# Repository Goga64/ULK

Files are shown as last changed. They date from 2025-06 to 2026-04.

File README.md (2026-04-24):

# ULK

Low profile split keyboard with Corne 42 Layout and Cherry ULP switches. Made to be used on top of a laptop keyboard to provide the ultimate split experience on the go. 

## Contents
   - [Description](#Description)
   - [Gallery](#Gallery)
   - [BOM](#BOM)
   - [Firmware](#Firmware)
   - [Inspirations](#Inspirations)
     
169full
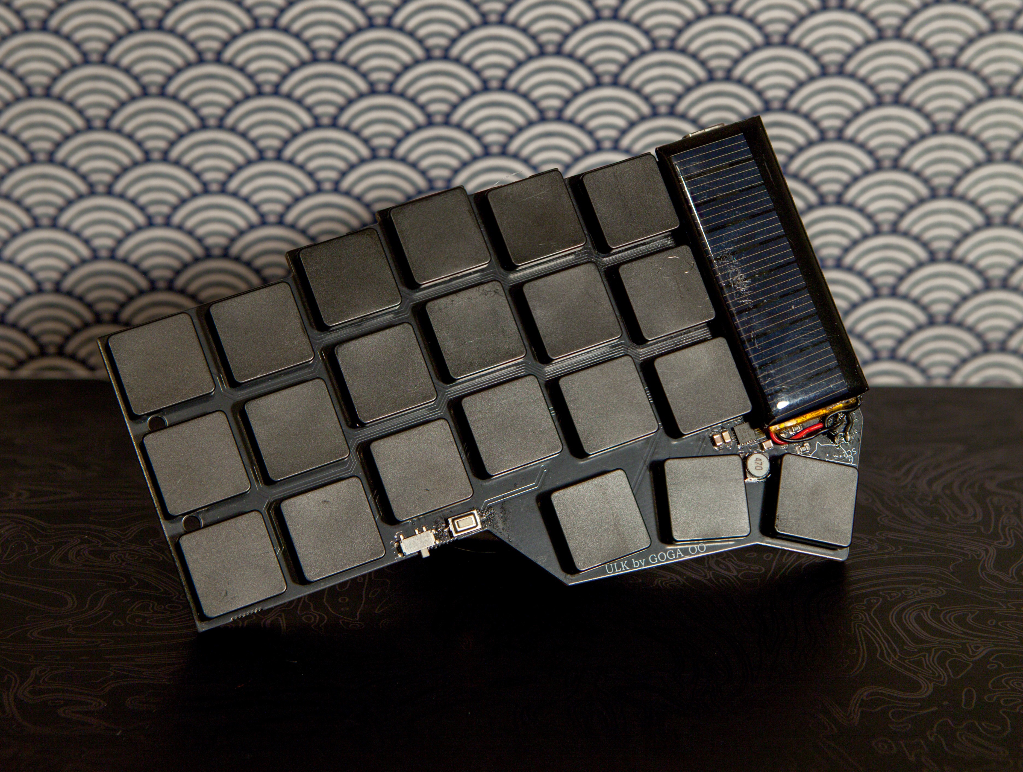
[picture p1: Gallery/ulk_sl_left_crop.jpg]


# Description

## Switches
### Sound  
I have recorded some [samples](https://github.com/Goga64/ULK/tree/e7978e2b8ab778f136db2aed6a6b6116afc4dded/Sound). For all of them the keyboard was on a mousepad.

I prefer the sound of the ULP Click, although it is still not as nice as the full size switches.

### Feel
The Cherry ULP feel quite satifying to type on, however they are a bit heavy coming in at 65g. The PG1316s though I'm not as impressed by, I got the 35g version which is very light, it makes the typing feel effortless, it doesn't really feel like anything. With it I also struggle with typos while writing as extra letters will just appear out of nowhere. It is definetry something I need to get used to before I can give a better oppinion. I will probably want to try the 60g version of them in the future and if they made a 50g version I would build another keeb with them immediately.  

## Firmware
The non-solar versions use standard Conre ZMK firmware.

The solar version however is diodeless, thus it is direct wired. So you should use my a modified verion of the MC Technology's zmk-config [GitHub link](https://github.com/Goga64/zmk-config-ULK)

The firmware was one of the biggest roadblock in getting the whole thing working. As it has 21 keys per side it uses all of the GPIO avaliable on a ProMicro including three marked purple here:



As they are not included in the original pinout on the main ZMK branch I needed fork and change the [pinout](https://github.com/Goga64/zmk/blob/v0.3-branch/app/boards/arm/nice_nano/arduino_pro_micro_pins.dtsi) to include them. 

I have also not wired up both sides as a mirror of each other on the PCB which has lead to a weird [keymap_transform](https://github.com/Goga64/zmk-config-ULK/blob/7f940e578cdd5d7742a9fed1b120f3a784b748a8/boards/shields/ulk_sl/ulk_sl.dtsi).

## Things to do: 
   - Add a 3x5 option.
   - Update BOM for sl version
   - Solar writeup

## Gallery
More images can be found in the [Gallery folder](https://github.com/Goga64/ULK/tree/953767bf9aa2bdcd04b6005427a60ab565788cff/Gallery).
They were taken on a Cannon EOS5D mkii (2008) and an EF 24-70mm F/2.8 USM lens.

I had a lot of fun focus stacking them for the best sharpness.

# BOM 

## Main Components (for the non solar version)

| Name | Specification | Notes |
|---|---|---|
| Switches | Cherry ULP or Kailh PG1316S | You can find more about the ULP at [Cherry_MX_ULP](https://github.com/pashutk/Cherry_MX_ULP) |
| Keycaps | 1U Kailh PG1316S Keycaps | — |
| Diodes | 1N4148W in SOD-123 package | — |
| Microcontroller  | SuperMini NRF52840 | Compatible with nice!nano V2 and alternatives ([GitHub link](https://github.com/joric/nrfmicro/wiki/Alternatives)) |
| Power switch | 7Pin Mini Slide Switch | — |
| Reset button | 3x6x4.3mm push button | Will change to an smd one after testing samples |
| Battery | ~100mAh 401525 LiPo or smaller | Prototype photos show 750mAh HiV battery due to shipping delays |

## Optional Components

| Name | Specification | Notes |
|---|---|---|
| Non-slip | 1 mm Silicone Rubber Strip, Self Adhesive | Increases overall thickness to 6.8mm |
| Kapton tape | Polyimide insulating tape | To cover through-hole components on bottom of PCB |

<!---
## BOM
Switches - Cherry ULP or Khali PG1316S
Keycaps - 1U Kailh PG1316S Keycaps 
Diodes - 1N4148W in SOD-123 package
Microcontroller - SuperMini NRF52840 - compatable with nice!nano V2 and it's alternatives https://github.com/joric/nrfmicro/wiki/Alternatives
Power switch - 7Pin Mini Slide Switch
Reset button -  3x6x4.3mm push button - Will probably be changed, when I get a sample of buttons.
Battery - ~100mAh 401525 Lipo or smaller - On the pictures a 750 mAh HiV battery is used due to battery shipping taking a long time and I had those lying around.

Optional
Non-slip - 1 mm Silicone Rubber Strip Self Adhesive (thinkness increases to 6.8mm).
Capton tape - to cover the through hole components on the bottom side of the pcb.
-->

## Inspirations
- [foostan/crkbd](https://github.com/foostan/crkbd)
- [mctechnology17/zmk-config](https://github.com/mctechnology17/zmk-config)
- [pashutk/Cherry_MX_ULP](https://github.com/pashutk/Cherry_MX_ULP)
- [zmk-config-mikefive](https://github.com/mikeholscher/zmk-config-mikefive)
- [ZMK](https://zmk.dev/)

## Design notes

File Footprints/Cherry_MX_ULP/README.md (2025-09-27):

# Cherry MX ULP (Ultra Low Profile) Switches & Custom Keyboard Builds

From https://github.com/pashutk/Cherry_MX_ULP

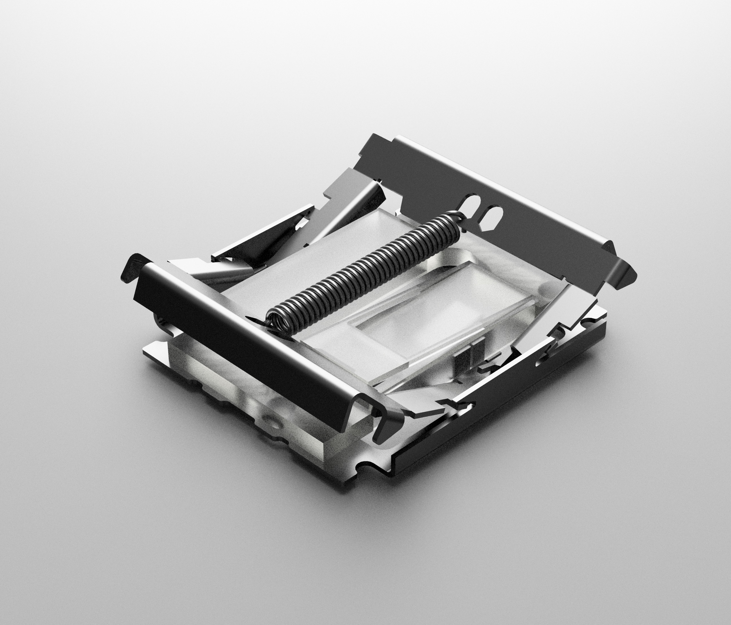
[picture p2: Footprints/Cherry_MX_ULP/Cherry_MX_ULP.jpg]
Cherry MX ULP switch 3d render


This repository serves as an extensive resource for all things related to Cherry MX Ultra Low Profile (Cherry MX ULP) switches. It provides crucial information on custom keyboard builds using these switches, KiCad footprints for various switch configurations, datasheets, sources for keycaps, related projects, and purchase options.

## Contents

- [KiCad Footprints](#kicad-footprints--3d-model)
- [Datasheets](#datasheets)
- [Keycaps](#keycaps)
- [Projects Using ULP Switches](#projects-using-cherry-mx-ulp-switches)
- [Where to Buy ULP Switches](#where-to-buy-cherry-mx-ulp-switches)

## KiCad Footprints & 3D model

This repo contains KiCad footprints for:

- SMD Mounted Switches
- SMD Mounted Double-Sided
- Through-Hole Mounted (Hand Soldering)
- Through-Hole Mounted Double-Sided

**Please note that the double-sided mounts are still in the testing phase and might be subject to change.**

The repo also contains a 3D model of the switch [in a STEP format](https://github.com/pashutk/Cherry_MX_ULP/blob/main/Cherry_ULP.pretty/Cherry_MX_ULP.step). The model has limited dimensional precision and should only be used for visualization purposes.

## Datasheets

Although the datasheets we have currently are not highly detailed, they provide the essential specifications and information required for working with Cherry MX ULP switches. More comprehensive data will be added as they become available.

- [Cherry MX Ultra Low Profile Click](https://github.com/pashutk/Cherry_ULP/blob/main/CHERRY_MX_ULP_Click_Datasheet.pdf)
- [Cherry MX Ultra Low Profile Tactile](https://github.com/pashutk/Cherry_ULP/blob/main/CHERRY_MX_ULP_Tactile_Datasheet.pdf)

### Patents

For deeper understanding, it could be beneficial to look at related patents by Cherry. Although the following patent does not directly pertain to the exact model of the Cherry MX ULP switches, the general design principles are very similar:

- [Key module for a keyboard, and keyboard](https://patents.google.com/patent/US20230154700A1/en?inventor=Eduard+Ruff&sort=new)

These patents can serve as great resources for technical understanding and innovation around switch designs.

## Keycaps

### Where to source

Acquiring the right keycaps for Cherry MX ULP switches involves several potential sources:

1. **Off-the-shelf Keyboards**: Keycaps can be harvested from the following keyboards:
    - [Corsair K100 AIR WIRELESS RGB Ultra-Thin Mechanical Gaming Keyboard](https://www.corsair.com/ww/en/p/keyboards/ch-913a01u-ch/k100-air-wireless-rgb-ultra-thin-mechanical-gaming-keyboard-cherry-mx-ultra-low-profile-tactile-ch-913a01u-ch)
    - [Cherry KW X ULP](https://www.cherryamericas.com/kw-x-ulp)
    - [Mistel Air One](http://mistelkeyboard.com/products/9a36520f591f4f8b8e1253abf6885b51)
    - [KeyPulse Elite](https://www.kickstarter.com/projects/1658898886/keypulse-elite-slim-mechanical-keyboards/description)

2. **Dell Alienware Laptop Keyboard Module**: This module can also be used as a donor for keycaps. You can find it [here](https://www.aliexpress.com/item/1005005578673316.html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).

3. **3D Printing**: At this moment, 3D printing of custom keycaps for Cherry MX ULP switches requires additional, more detailed datasheets directly from Cherry. Despite this, there have been successful attempts at creating 3D printed keycaps:
    - [Mask Keyboard](https://www.reddit.com/r/ErgoMechKeyboards/comments/zpo9h6/mask200_4x6_split_keyboard_with_cherry_mxulp_keys/) by [marcoster](https://github.com/marcoster)
    - [Several keycap designs](https://www.thingiverse.com/thing:6058656) by [Alescito](https://www.thingiverse.com/alescito/designs)
    - [Cairn Mesa Keyboard](https://gitlab.cairn-devices.eu/cairntech/cairn-mesa-key) by [Cairn Devices](https://www.cairn-devices.eu/)

### Dimensions and photos

| Name | WxHxD, mm | Profile | HS, mm | HPS, mm | S, mm | Photo |
|---|---|---|---|---|---|---|
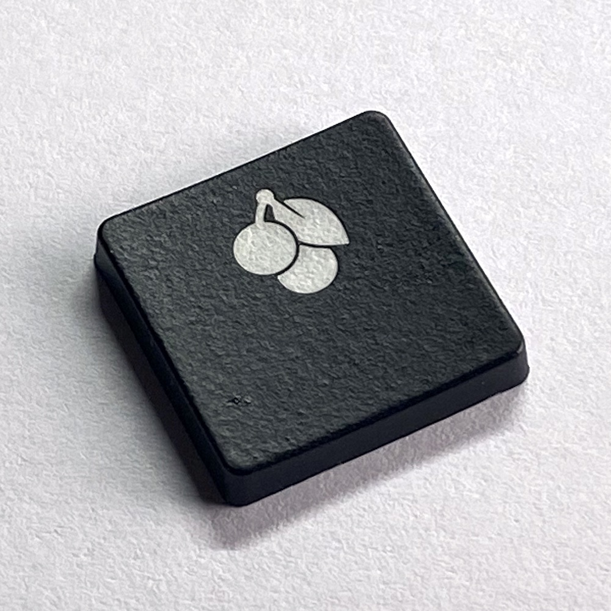
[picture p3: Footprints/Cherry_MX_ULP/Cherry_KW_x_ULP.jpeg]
Cherry KW x ULP keycap
| Cherry KW x ULP | 15.2x15.2x2.55 | Concave Cylindrical | 4.85 | 2.68 | 3.9 |  |
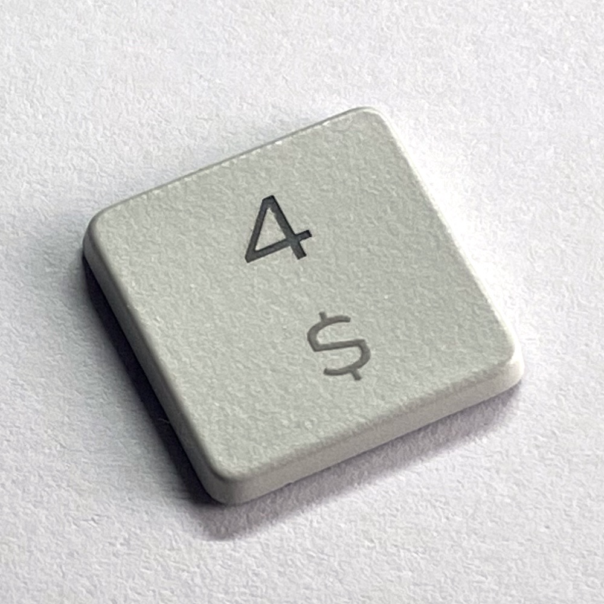
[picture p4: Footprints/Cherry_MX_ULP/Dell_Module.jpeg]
Dell Module keycap
| Dell Module | 15.9x15.9x1.72 | Flat | 4.5 | 2.54 | 3 |  |
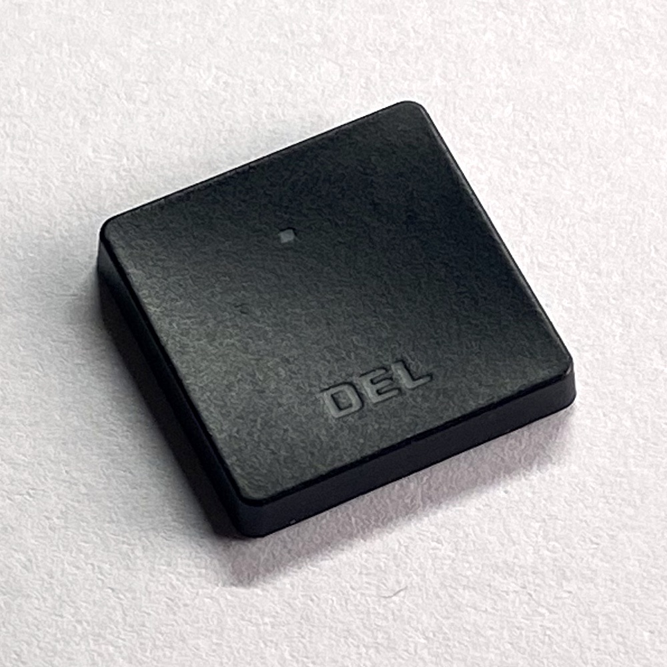
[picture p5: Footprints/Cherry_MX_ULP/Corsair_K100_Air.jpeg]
Corsair K100 Air keycap
| Corsair K100 Air | 16x16x2.7 | Concave Spherical | 5 | 3 | 3 |  |
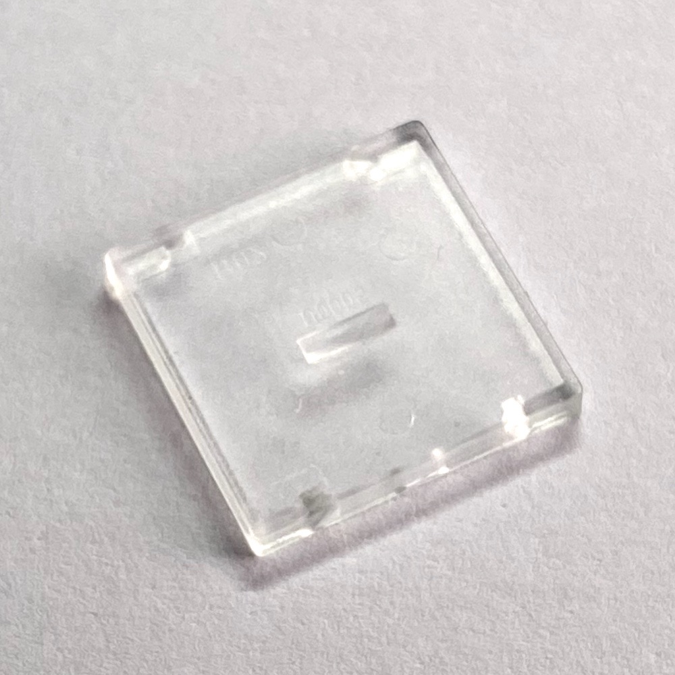
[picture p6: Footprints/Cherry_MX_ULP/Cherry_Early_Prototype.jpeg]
Cherry Early Prototype
| Cherry Early Prototype | 15x15x1.8 | Flat | 4 | 2.12 | - |  |
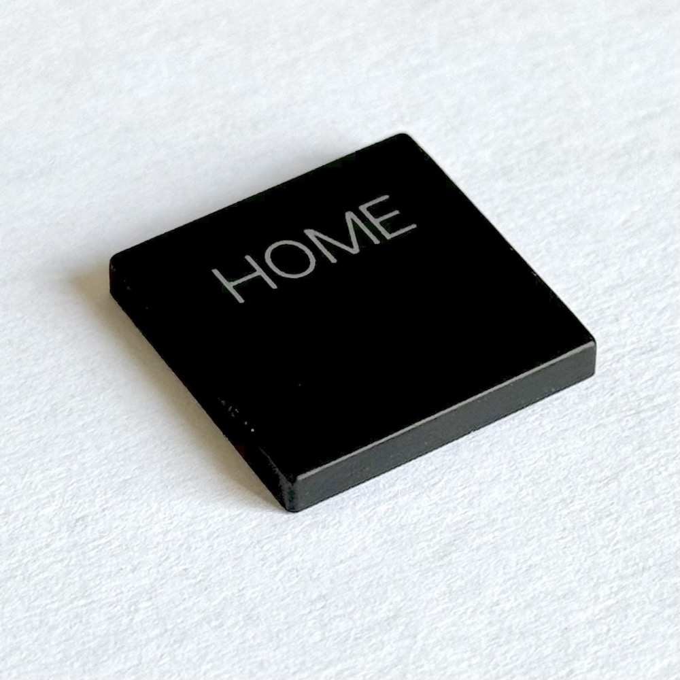
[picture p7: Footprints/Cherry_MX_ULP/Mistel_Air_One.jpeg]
Mistel Air One
| Mistel Air One | 16.1x16.2.25 | Flat | 4.4 | 2.5 | 2.8 |  |

- HS – height of a keycap with a switch
- HPS – height of a keycap with a pressed switch
- S – spacing, distance between keycaps

### Removing Keycaps Without Damage

To get a 1u keycap from a switch without causing too much damage, follow these steps:

- Gently pry off from the bottom left side and then the bottom right side using tweezers.
- To reduce the potential for damage, gently push the keycap from the opposite side using your fingertip.
- The keycap should be free from one side with a click sound, and then you can take it off the switch.

Non-1u keys are a bit trickier because they may use stabilizer bars and additional stabilizers, but the principle stays the same.

## Projects Using Cherry MX ULP Switches

For inspiration or technical insight, check out these projects that incorporate Cherry MX ULP switches in their keyboard builds, created by some innovative members of the community:

### Keyboard Builds
1. [Mask Keyboard](https://www.reddit.com/r/ErgoMechKeyboards/comments/zpo9h6/mask200_4x6_split_keyboard_with_cherry_mxulp_keys/) by [marcoster](https://github.com/marcoster)
2. [Cairn Mesa Keyboard](https://gitlab.cairn-devices.eu/cairntech/cairn-mesa-key) by the team at [Cairn Devices](https://www.cairn-devices.eu/)
3. [ULPpad](https://t.me/s/pashutkkb/60) by [pashutk](https://github.com/pashutk)
4. [ULP-Dactyl](https://github.com/jonboh/ulp-dactyl) by [jonboh](https://github.com/jonboh)
5. [mnhTTn](https://github.com/fooker/mnhttn) by [fooker](https://github.com/fooker)
6. [btrfld_ulp](https://github.com/SolidHal/btrfld) by [SolidHal](https://github.com/SolidHal)

### Custom Components and Techniques
1. Interesting take on [handwiring using point pins](https://www.reddit.com/r/ErgoMechKeyboards/comments/18qr1xp/cherry_ulp_prototyping/) by [Magnus Ascathon](https://www.reddit.com/user/Magnus_Ascathon/)
2. Single key PCBs [Amoeba Cherry ULP](https://github.com/jonboh/amoeba-cherry-ulp) by [jonboh](https://github.com/jonboh)

This list is not exhaustive, and we welcome contributions from the community. If you know of or have developed a project using Cherry MX ULP switches that is not listed here, please refer to the [Contribution](#contribution) section for information on how to share your work with the community.

## Where to Buy Cherry MX ULP Switches

If you're ready to start your own project, below are links to stores where you can purchase Cherry MX ULP switches:

1. [Reichelt Elektronik](https://www.reichelt.de/de/en/cherry-mx-ultra-low-profile-rgb-pushbutton-module-cherry-mx6c-k3nb-p335040.html) - Germany, EU
2. [Taobao](https://detail.1688.com/offer/681367194838.html) - Shenzhen, China

Remember, availability can vary based on your location and the store's stock levels.

## Contribution

We're always looking for more information about Cherry MX ULP switches. If you have information to share or would like to contribute to the development of the KiCad footprints, please open an issue or submit a pull request.

## License

This project is licensed under the MIT License. This means you're free to use, copy, modify, merge, publish, distribute, sublicense, and/or sell copies of any materials in this project. However, you must provide appropriate attribution to the original author.

For more details, please refer to the [LICENSE](LICENSE) file in this repository.

## Disclaimer

This is an independent project and has not been authorized, sponsored, or otherwise approved by Cherry or any other parties. We do not take any responsibility for any damages or legal issues that may arise from using the information provided in this repository. Use it at your own risk.

---

Remember, this is a living document. Check back often for updates and new information. We're excited to see what you build with Cherry MX ULP switches!

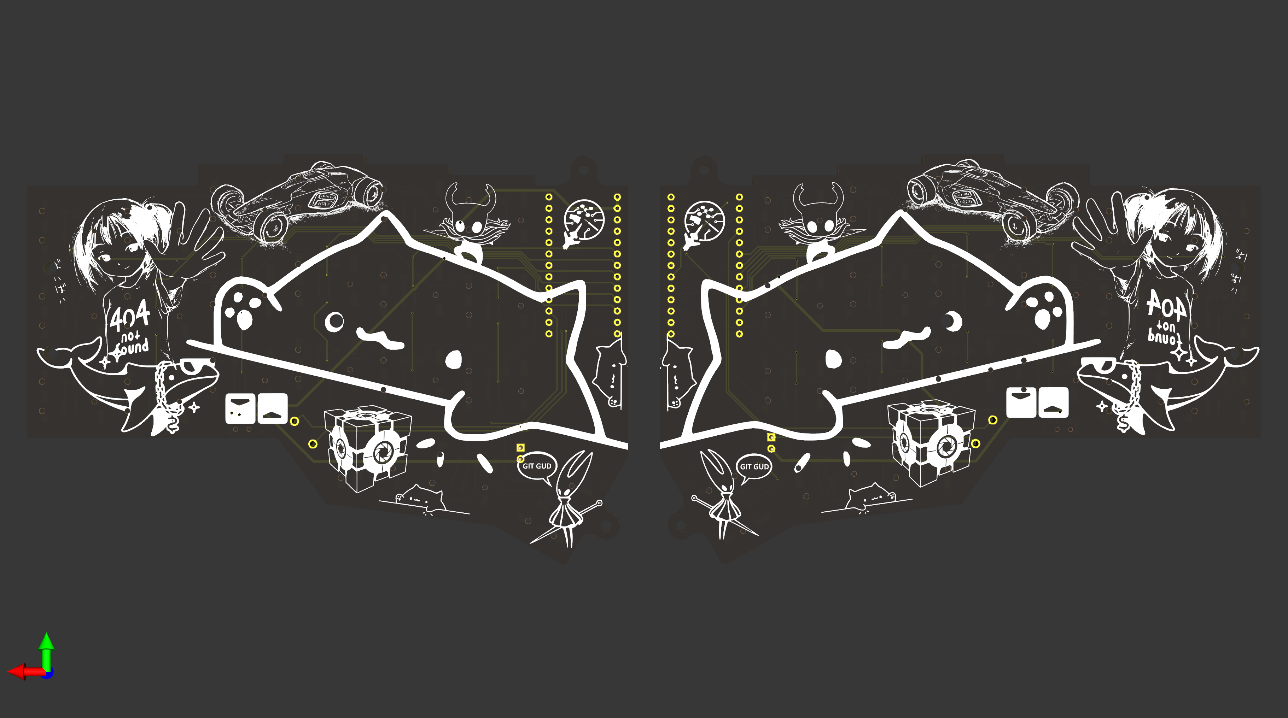
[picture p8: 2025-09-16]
Renders/ULK_back.png

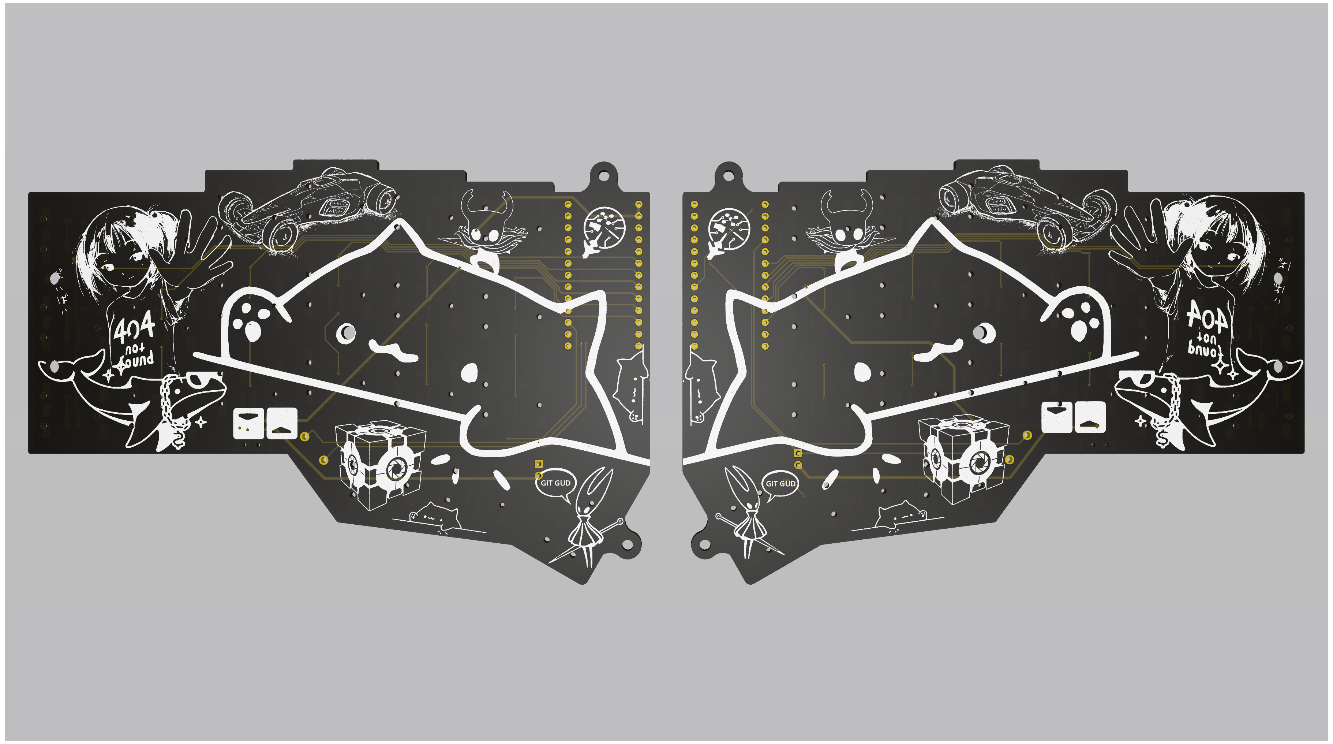
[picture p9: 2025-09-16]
Renders/ULK_backr.png

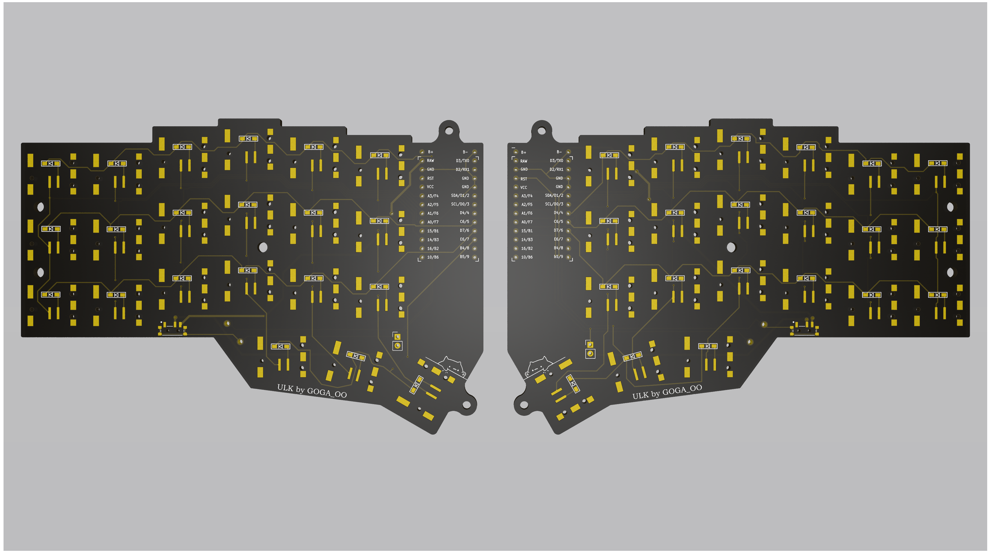
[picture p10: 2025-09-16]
Renders/ULK_frontr.png

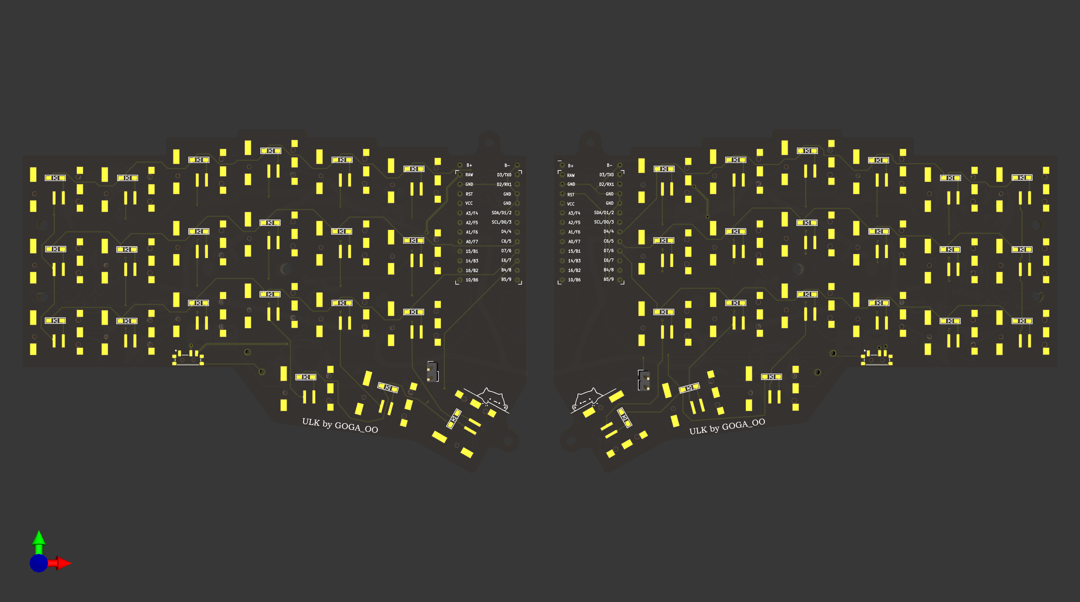
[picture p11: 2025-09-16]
Renders/ULK_front.png

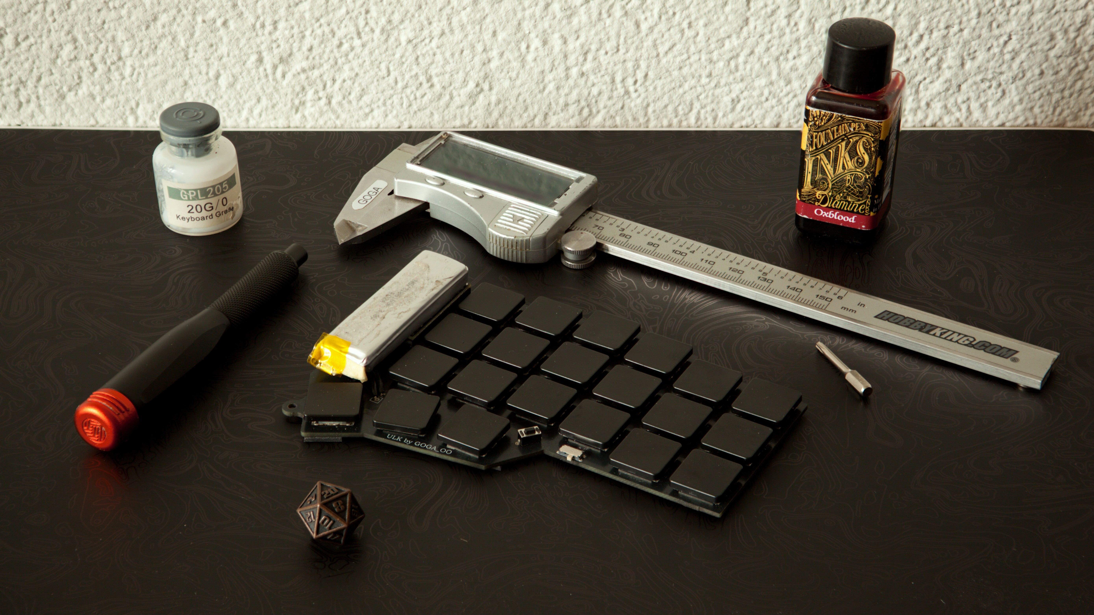
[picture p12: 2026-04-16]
Gallery/169fullll.jpg

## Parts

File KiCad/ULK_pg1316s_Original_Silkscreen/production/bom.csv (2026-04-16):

Designator | Footprint | Quantity | Value | LCSC Part #
D1, D10, D11, D12, D13, D14, D15, D16, D17, D18, D19, D2, D20, D21, D22, D23, D24, D25, D26, D27, D28, D29, D3, D30, D31, D32, D33, D34, D35, D36, D37, D38, D39, D4, D40, D41, D42, D5, D6, D7, D8, D9 | D3_SMD_v2 | 42 | D
MOUSE-BITE-2MM-SLOT_8, MOUSE-BITE-2MM-SLOT_7, MOUSE-BITE-2MM-SLOT_6, MOUSE-BITE-2MM-SLOT_5, MOUSE-BITE-2MM-SLOT_4, MOUSE-BITE-2MM-SLOT_3, MOUSE-BITE-2MM-SLOT_2, MOUSE-BITE-2MM-SLOT | mouse-bite-2mm-slot | 8 | VAL**
RSW1, RSW2 | ResetSW_1side | 2 | SW_PUS
SW1, SW10, SW11, SW12, SW13, SW14, SW15, SW16, SW17, SW18, SW19, SW2, SW20, SW21, SW22, SW23, SW24, SW25, SW26, SW27, SW28, SW29, SW3, SW30, SW31, SW32, SW33, SW34, SW35, SW36, SW37, SW38, SW39, SW4, SW40, SW41, SW42, SW5, SW6, SW7, SW8, SW9 | CPG1316S01D02_kailhspecsheet_mikefive | 42 | SW_PUSH
SW43, SW44 | SW_PCM12SMTR | 2 | PCM12SMTR
U1, U2 | ProMicro_v3 | 2 | ProMicro
U3, U5 | PinHeader_1x02_P2.54mm_Vertical | 2 | ~

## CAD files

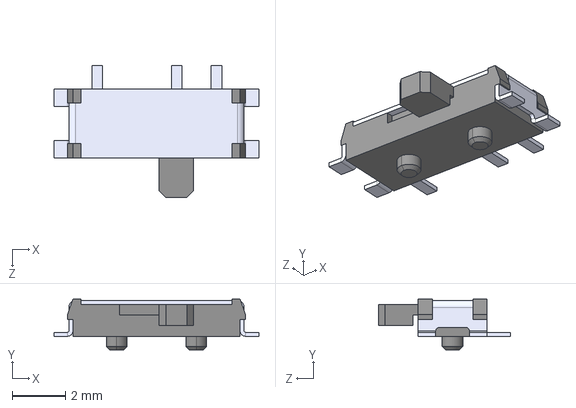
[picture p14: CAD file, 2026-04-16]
Footprints/PCM12SMTR/PCM12SMTR.step
7.72 x 1.91 x 4.98 mm

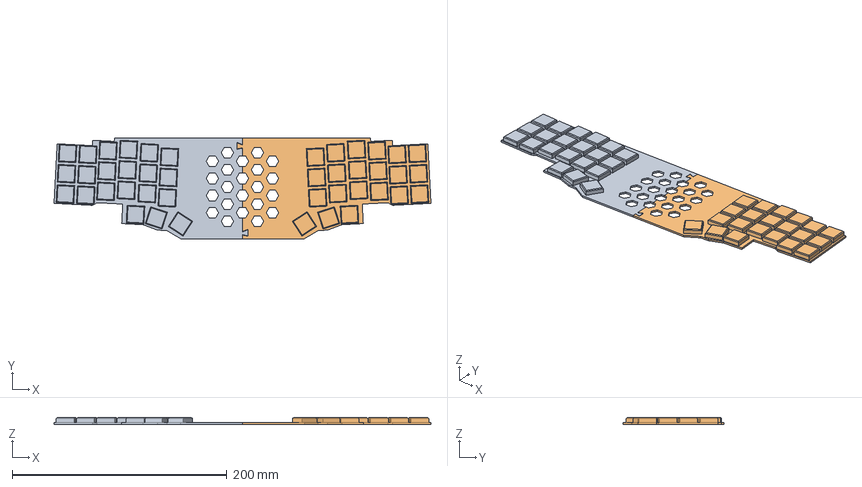
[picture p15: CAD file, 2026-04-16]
KiCad/ULK_sl_PG1316s/3d/visiual rep.step
351.3 x 93.7 x 6.10 mm

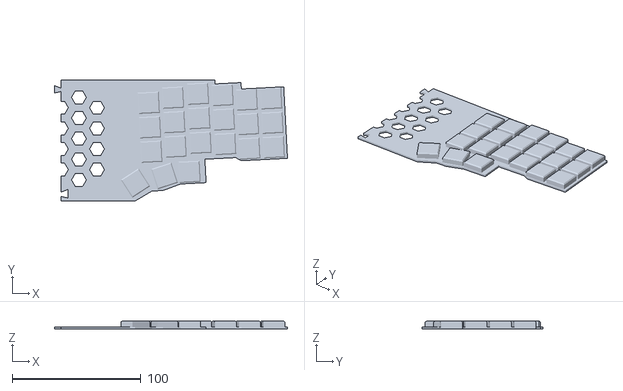
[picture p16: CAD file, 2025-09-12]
KiCad/ULK_sl_PG1316s/3d/R.rev1.stl
180.7 x 93.7 x 6.10

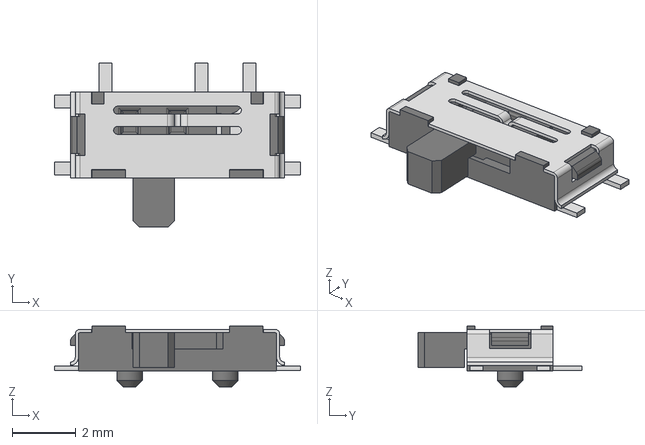
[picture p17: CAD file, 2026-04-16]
KiCad/ULK_sl_PG1316s/450404015514.stp
7.70 x 5.13 x 1.90 mm

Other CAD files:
KiCad/ULK_sl_PG1316s/3d/L.rev1.stl
3d/R.rev1.stl
3d/L.rev1.stl
3d/visiual rep.step

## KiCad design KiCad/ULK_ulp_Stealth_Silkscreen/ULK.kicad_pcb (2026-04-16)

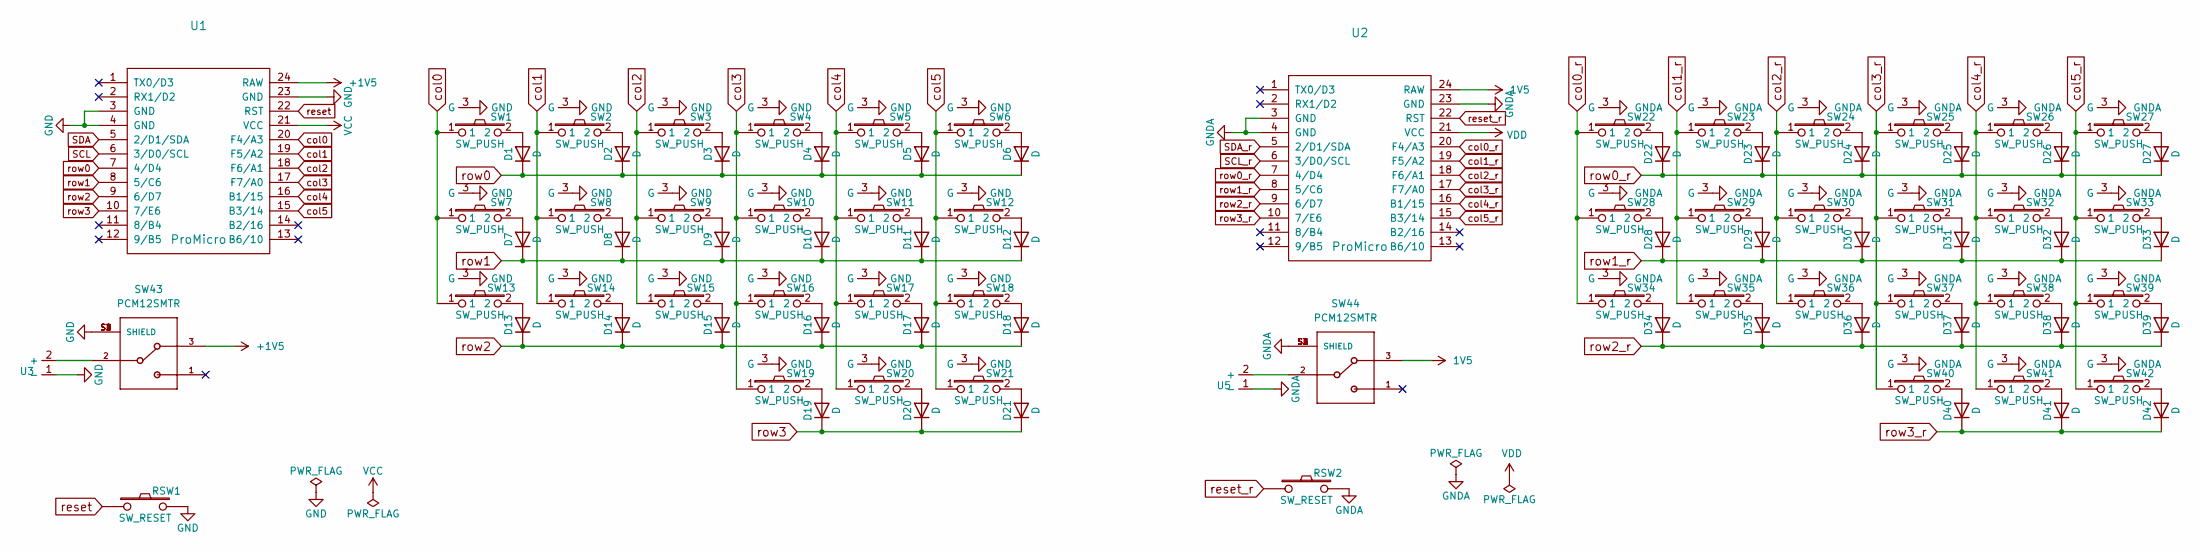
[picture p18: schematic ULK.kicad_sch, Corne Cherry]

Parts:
D1, D2, D3, D4, D5, D6, D7, D8, D9, D10, D11, D12, D13, D14, D15, D16, D17, D18, D19, D20, D21, D22, D23, D24, D25, D26, D27, D28, D29, D30, D31, D32, D33, D34, D35, D36, D37, D38, D39, D40, D41, D42: D; D3_SMD_v2
RSW1, RSW2: SW_RESET; ResetSW_1side
SW1, SW2, SW3, SW4, SW5, SW6, SW7, SW8, SW9, SW10, SW11, SW12, SW13, SW14, SW15, SW16, SW17, SW18, SW19, SW20, SW21, SW22, SW23, SW24, SW25, SW26, SW27, SW28, SW29, SW30, SW31, SW32, SW33, SW34, SW35, SW36, SW37, SW38, SW39, SW40, SW41, SW42: SW_PUSH; Cherry_ULP_SMD
SW43, SW44: PCM12SMTR; SW_PCM12SMTR
U1, U2: ProMicro; ProMicro_v3
U3, U5: PinHeader_1x02_P2.54mm_Vertical

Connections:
1V5: SW44.3, U2.24 (RAW)
+1V5: SW43.3, U1.24 (RAW)
GND: RSW1.2, SW1.3 (G), SW2.3 (G), SW3.3 (G), SW4.3 (G), SW5.3 (G), SW6.3 (G), SW7.3 (G), SW8.3 (G), SW9.3 (G), SW10.3 (G), SW11.3 (G), SW12.3 (G), SW13.3 (G), SW14.3 (G), SW15.3 (G), SW16.3 (G), SW17.3 (G), SW18.3 (G), SW19.3 (G), SW20.3 (G), SW21.3 (G), SW43.S1 (SHIELD), SW43.S2 (SHIELD), SW43.S3 (SHIELD), SW43.S4 (SHIELD), U1.3 (GND), U1.4 (GND), U1.23 (GND), U3.1 (-)
GNDA: RSW2.2, SW22.3 (G), SW23.3 (G), SW24.3 (G), SW25.3 (G), SW26.3 (G), SW27.3 (G), SW28.3 (G), SW29.3 (G), SW30.3 (G), SW31.3 (G), SW32.3 (G), SW33.3 (G), SW34.3 (G), SW35.3 (G), SW36.3 (G), SW37.3 (G), SW38.3 (G), SW39.3 (G), SW40.3 (G), SW41.3 (G), SW42.3 (G), SW44.S1 (SHIELD), SW44.S2 (SHIELD), SW44.S3 (SHIELD), SW44.S4 (SHIELD), U2.3 (GND), U2.4 (GND), U2.23 (GND), U5.1 (-)
unnamed: D1.2 (A), SW1.2
unnamed: D2.2 (A), SW2.2
unnamed: D3.2 (A), SW3.2
unnamed: D4.2 (A), SW4.2
unnamed: D5.2 (A), SW5.2
unnamed: D6.2 (A), SW6.2
unnamed: D7.2 (A), SW7.2
unnamed: D8.2 (A), SW8.2
unnamed: D9.2 (A), SW9.2
unnamed: D10.2 (A), SW10.2
unnamed: D11.2 (A), SW11.2
unnamed: D12.2 (A), SW12.2
unnamed: D13.2 (A), SW13.2
unnamed: D14.2 (A), SW14.2
unnamed: D15.2 (A), SW15.2
unnamed: D16.2 (A), SW16.2
unnamed: D17.2 (A), SW17.2
unnamed: D18.2 (A), SW18.2
unnamed: D19.2 (A), SW19.2
unnamed: D20.2 (A), SW20.2
unnamed: D21.2 (A), SW21.2
unnamed: D22.2 (A), SW22.2
unnamed: D23.2 (A), SW23.2
unnamed: D24.2 (A), SW24.2
unnamed: D25.2 (A), SW25.2
unnamed: D26.2 (A), SW26.2
unnamed: D27.2 (A), SW27.2
unnamed: D28.2 (A), SW28.2
unnamed: D29.2 (A), SW29.2
unnamed: D30.2 (A), SW30.2
unnamed: D31.2 (A), SW31.2
unnamed: D32.2 (A), SW32.2
unnamed: D33.2 (A), SW33.2
unnamed: D34.2 (A), SW34.2
unnamed: D35.2 (A), SW35.2
unnamed: D36.2 (A), SW36.2
unnamed: D37.2 (A), SW37.2
unnamed: D38.2 (A), SW38.2
unnamed: D39.2 (A), SW39.2
unnamed: D40.2 (A), SW40.2
unnamed: D41.2 (A), SW41.2
unnamed: D42.2 (A), SW42.2
unnamed: SW43.2, U3.2 (+)
unnamed: SW44.2, U5.2 (+)
SCL: U1.6 (3/D0/SCL)
SCL_r: U2.6 (3/D0/SCL)
SDA: U1.5 (2/D1/SDA)
SDA_r: U2.5 (2/D1/SDA)
VCC: U1.21 (VCC)
VDD: U2.21 (VCC)
col0: SW1.1, SW7.1, SW13.1, U1.20 (F4/A3)
col0_r: SW22.1, SW28.1, SW34.1, U2.20 (F4/A3)
col1: SW2.1, SW8.1, SW14.1, U1.19 (F5/A2)
col1_r: SW23.1, SW29.1, SW35.1, U2.19 (F5/A2)
col2: SW3.1, SW9.1, SW15.1, U1.18 (F6/A1)
col2_r: SW24.1, SW30.1, SW36.1, U2.18 (F6/A1)
col3: SW4.1, SW10.1, SW16.1, SW19.1, U1.17 (F7/A0)
col3_r: SW25.1, SW31.1, SW37.1, SW40.1, U2.17 (F7/A0)
col4: SW5.1, SW11.1, SW17.1, SW20.1, U1.16 (B1/15)
col4_r: SW26.1, SW32.1, SW38.1, SW41.1, U2.16 (B1/15)
col5: SW6.1, SW12.1, SW18.1, SW21.1, U1.15 (B3/14)
col5_r: SW27.1, SW33.1, SW39.1, SW42.1, U2.15 (B3/14)
reset: RSW1.1, U1.22 (RST)
reset_r: RSW2.1, U2.22 (RST)
row0: D1.1 (K), D2.1 (K), D3.1 (K), D4.1 (K), D5.1 (K), D6.1 (K), U1.7 (4/D4)
row0_r: D22.1 (K), D23.1 (K), D24.1 (K), D25.1 (K), D26.1 (K), D27.1 (K), U2.7 (4/D4)
row1: D7.1 (K), D8.1 (K), D9.1 (K), D10.1 (K), D11.1 (K), D12.1 (K), U1.8 (5/C6)
row1_r: D28.1 (K), D29.1 (K), D30.1 (K), D31.1 (K), D32.1 (K), D33.1 (K), U2.8 (5/C6)
row2: D13.1 (K), D14.1 (K), D15.1 (K), D16.1 (K), D17.1 (K), D18.1 (K), U1.9 (6/D7)
row2_r: D34.1 (K), D35.1 (K), D36.1 (K), D37.1 (K), D38.1 (K), D39.1 (K), U2.9 (6/D7)
row3: D19.1 (K), D20.1 (K), D21.1 (K), U1.10 (7/E6)
row3_r: D40.1 (K), D41.1 (K), D42.1 (K), U2.10 (7/E6)

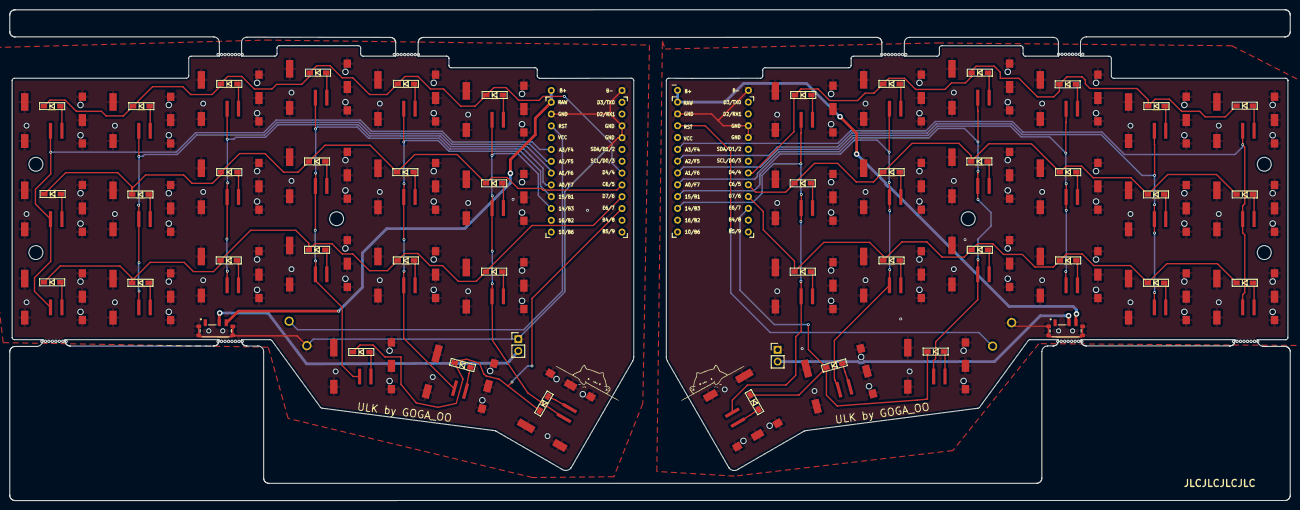
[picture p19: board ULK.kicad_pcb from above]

Board: 2 copper layers, 275.5 x 105.6 mm, 100 parts (0 on the bottom side), 70 nets.

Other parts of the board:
mouse-bite-2mm-slot, mouse-bite-2mm-slot#2, mouse-bite-2mm-slot#3, mouse-bite-2mm-slot#4, mouse-bite-2mm-slot#5, mouse-bite-2mm-slot#6, mouse-bite-2mm-slot#7, mouse-bite-2mm-slot#8: VAL**; mouse-bite-2mm-slot

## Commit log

2025-06-16 Revert "Add files via upload"
    This reverts commit 6f8d5c44d196924c14e02aa596787fb68a29ea2a.
    [visiual rep.step]
2025-09-17 gound planes
    [ULK.kicad_pcb, ULK.kicad_sch, bom.csv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]
2025-09-17 ulp update ground plane
2025-09-17 ulp gound plane
    [ULK.kicad_sch, bom.csv, designators.csv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]
2025-09-17 Added PG1316S pcb
    [ULK.kicad_pcb, ULK.kicad_sch, bom.csv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]
2025-10-12 pg1316s 1.0.3
    [ULK.kicad_pcb]
2026-04-16 Solar + restructuring
    [450404015514.stp, L.rev1.stl, PCM12SMTR.step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]
